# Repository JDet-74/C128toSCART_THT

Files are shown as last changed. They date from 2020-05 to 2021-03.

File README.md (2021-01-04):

<h2>C128toSCART_THT</h2>

<p>This is a project to connect a&nbsp;Commodore C128 8-bit computer to a display with a SCART input device.</p>

<p>Here, you can find some documents to build the video adapter PCB which I developed.</p>

<p>Get the information, build your PCB and have some 8-bit fun.</p>

<p>I started this project because I wanted to use my old Commodore 128DCR with a modern display.</p>

<p>I only had&nbsp;a 30-year-old SCART-cable that combines the 9 pin D-SUB RGBI connector and the 8 pin DIN connector for audio and video output.</p>

<p>I reverse engineered the old cable and got into this content. The Commodore 128DCR has 2 separate video chips.</p>

<p>The VIC-chip that provides the 40 column video mode in a composite and s-video signal and the VDC-chip that provides the 80 column video mode in a 5V TTL level RGBI signal.&nbsp;</p>

<p>It is possible to use the C128 with 2 displays. One display that supports RGBI for the 80 column mode and another display that supports composite or s-video for the 40 column mode.</p>

<p>I wanted just one display that supports both and that was the reason why I used&nbsp;the SCART interface.</p>

<p>The SCART standard provides RGB, composite, s-video and component (Y Pb&nbsp;Pr). It is possible to use only one display and to switch between the two column modes.</p>

<p>I researched and created a PCB that converts the digital 5V TTL 4 bit RGBI signal into a analog RGB signal. For that I used a <span style="font-family: Arial, Helvetica, sans-serif; font-size: 12px;">EEPLD (electrical erasable&nbsp;</span>&nbsp;programmable logic device) that converts the 4 bit RGBI color code into a 6 bit RGB color code. A resistor network adapts the TTL level to the analog RGB voltage level.</p>

<p>This all happens between the 9 pin D-SUB connector and the manual switch.</p>

<p>The composite or s-video signal goes from the C128 DIN connector straight through the switch.</p>

<p>The SWITCH is just for switching the right signals to the right pins of the SCART connector to run the display device.</p>

<p>In the following directories you will find the necessary files for the PCB, the soldering, the part list, the housing and the switch-extension.</p>

## Contact
For any questions (technical / experience), please use the issue tracking system of github.

## Pictures
<p>Now some pictures of the project.&nbsp;Enjoy!</p>

<hr />
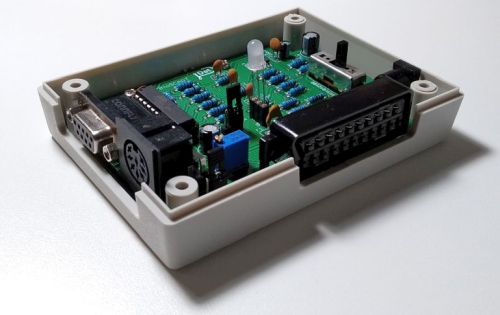
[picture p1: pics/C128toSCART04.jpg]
PCB in open housing


<p>This is the open housing with the soldered PCB mounted in</p>

<hr />
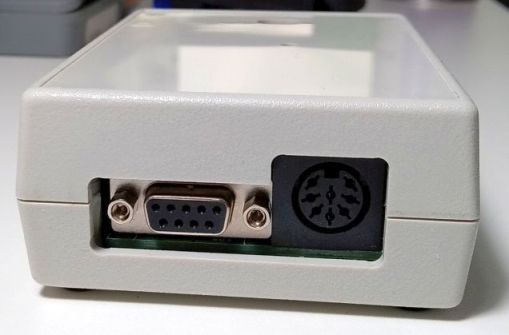
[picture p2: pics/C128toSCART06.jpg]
closed housing - connections to the C128


<p>The closed housing with the connections sockets to the C128 (D-SUB for RGBI &amp; DIN for the A/V Plug)</p>

<hr />
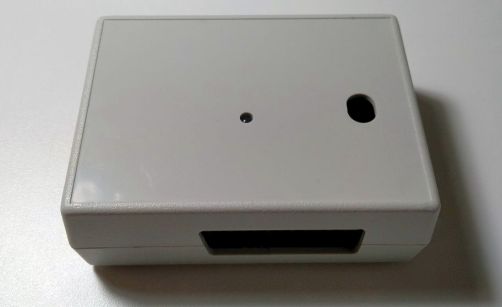
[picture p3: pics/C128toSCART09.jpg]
closed housing - the longhole for the switch-extension


<p>The view from above - the hole for the 3mm DUO-LED and the long hole for the switch-extension.<br />
It is also possible to toggle the switch with a pencil or something else ;)</p>

<hr />
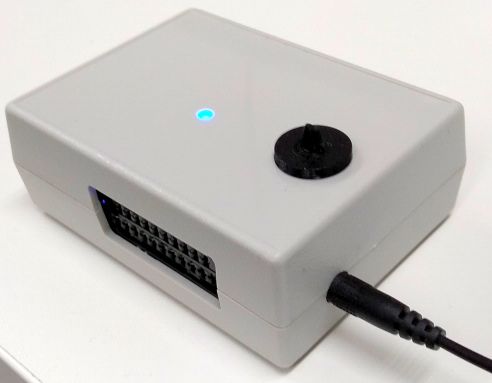
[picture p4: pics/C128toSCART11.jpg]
housing LED blue (80 column mode)


<p>The 3D printed switch-extension is plugged in.<br />
Device switched in 80 column mode (the blue LED indicates that) powered from a 5V USB-Charger with a barrel plug.<br />
It is possible to use the RGBI/CGA output of an&nbsp;old PC with a CGA graphic card to&nbsp; use a SCART display device.&nbsp;</p>

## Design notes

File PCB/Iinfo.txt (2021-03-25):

Take the Gerber_C128toSCART_V3.ZIP file and order the PCBs by your PCB manufaturer.
I ordered it be www.jlcpcb.com. The Gerber_C128toSCART_V3.ZIP contains the gerber files and this is all you need.

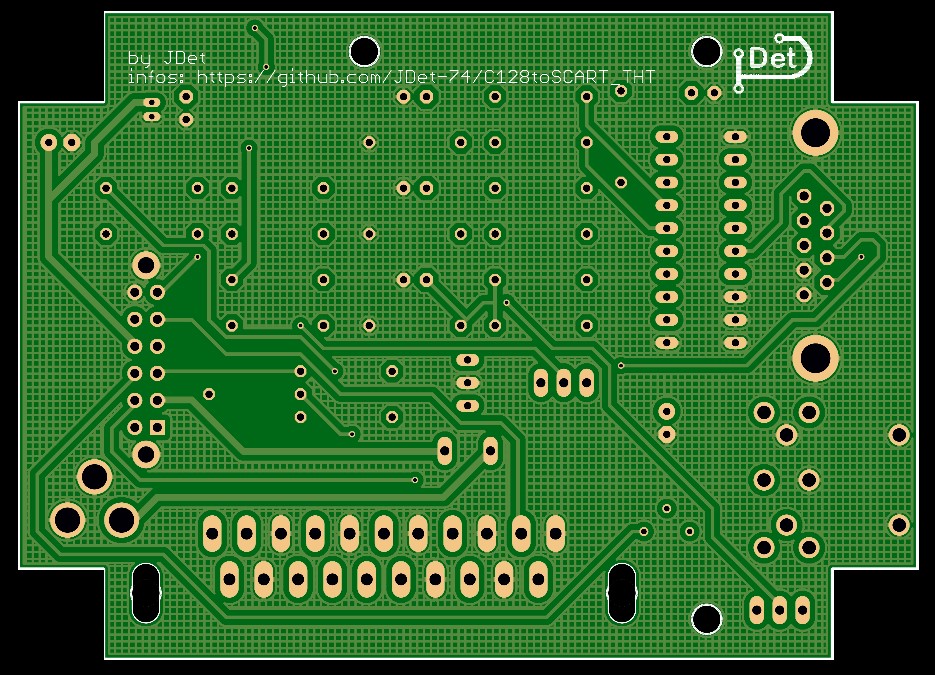
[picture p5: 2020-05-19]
PCB/PCB-C128toSCART-BOT.jpg

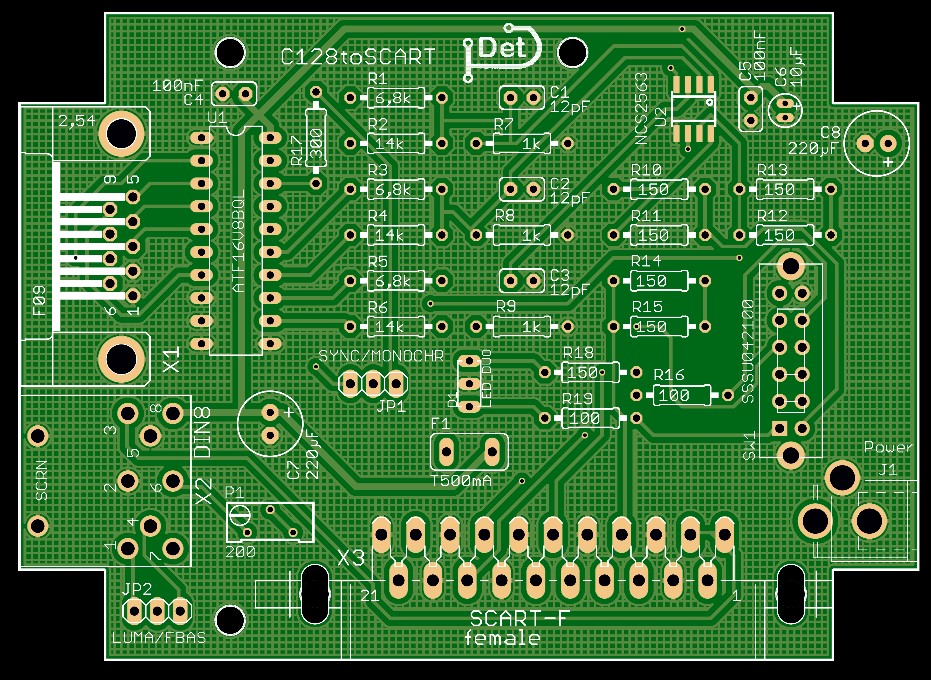
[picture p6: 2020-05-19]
PCB/PCB-C128toSCART-TOP.jpg

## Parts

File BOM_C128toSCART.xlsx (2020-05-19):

Pos | Name | Stück | Artikel # | Lieferant | Bezeichnung:
1 | option | 1 | RND 455-00959 | www.reichelt.de | Kunststoffgehäuse, 111 x 82,5 x 38 mm
2 | option | 1 | HS 25-14 | www.reichelt.de | Hohlstecker Knickschutz, Ø außen: 5,5 mm, Ø innen: 2,5 mm
3 | option | 1 | HSW 25-9 | www.reichelt.de | Hohlstecker ohne Knickschutz, Ø außen: 5,5 mm, Ø innen: 2,5 mm
4 | option | 2 | AK 218 SC | www.reichelt.de | D-SUB Kabel, 1:1, 9-pol., Stecker/Stecker, 1,8m
 | option | 1 | SBL 29065-100 | www.reichelt.de | Blechschrauben, PAN Head, PZD, 2,9 x 6,5 mm, 100 Stück
5 | option | 2 | MAS 80S | www.reichelt.de | DIN-Stecker 8-polig, Hufeisenform
6 | option | 1 | AK 315-10 | www.reichelt.de | Scart Kabel 21-pol Scart Stecker, 1 m
7 | R7-9 | 3 | C410696 | www.lcsc.com | Widerstand, Metallschicht, 1,0 kOhm, 0207, 0,6 W, 1%
8 | U1 | 1 | ATF 16V8BQL15 PU | www.reichelt.de | PLDs, 8 Makrozellen, 4,75 ... 5,25 V, DIL-20
9 | U1 | 1 | C2328 | www.lcsc.com | DIL20 Sockel (CHINA)
10 | option | 1 | RND 205-00643 | www.reichelt.de | RND Buchsenleiste, 3-pol, RM 2,54 mm
11 | JP1-2 | 2 | RND 205-00624 | www.reichelt.de | RND Stiftleiste, 3-pol, RM 2,54 mm
12 | P1 | 1 | 64Y-200 | www.reichelt.de | Präzisionspotentiometer, 25 Gänge, stehend, 200 Ohm
13 | option | 2 | JUMPER 2,54GL RT | www.reichelt.de | Kurzschlussbrücke, rot, mit Grifflasche
14 | R2,4,6 | 3 | C410680 | www.lcsc.com | Widerstand, Metallschicht, 14 kOhm, 0207, 0,6 W, 1%
15 | R10-15,18 | 7 | C410679 | www.lcsc.com | Widerstand, Metallschicht, 150 Ohm, 0207, 0,6 W, 1%
16 | D1 | 1 | C330762 | www.lcsc.com | LED, 3 mm, bedrahtet, 3-Pin CC, rot/grün, 80 mcd, 80°
17 | C4-5 | 2 | C353912 | www.lcsc.com | Ceramic Disc Capacitors 100nF -20%~+80% 50V Through Hole
18 | C1-3 | 3 | C353907 | www.lcsc.com | Keramik-Kondensator 12P
19 | R17 | 1 | C410638 | www.lcsc.com | Widerstand, Metallschicht, 300 Ohm, 0207, 0,6 W, 1%
20 | D1 | 1 | C331054 | www.lcsc.com | LED, 5 mm, bedrahtet, 3-Pin, rot/grün, 100 mcd, 30°
21 | R16,19 | 2 | C410697 | www.lcsc.com | Widerstand, Metallschicht, 100 Ohm, 0207, 0,6 W, 1%
22 | C7-8 | 2 | C43318 | www.lcsc.com | 220uF 10V
23 | R1,3,5 | 3 | C410590 | www.lcsc.com | Widerstand, Metallschicht, 6,8 kOhm, 0207, 0,6 W, 1%
24 | C6 | 1 | C43846 | www.lcsc.com | 10uF 25V 4*5
25 | SW1 | 1 | C384610 | www.lcsc.com | Toggle Switch (ALPS) (CHINA)
26 | U2 | 1 | C97773 | www.lcsc.com | NCS2563 - VIDEO AMP (CHINA)
27 | X1 | 1 | C75749 | www.lcsc.com | DSUB-9 Buchse
28 | X2 | 1 | DIN-8 Buchse | www.restore-store.de | DIN-8 Buchse Hufeisenform
29 | X3 | 1 | SCART Buchse | www.restore-store.de | SCART Buchse
30 | J1 | 1 | DC BU25 90 | www.reichelt.de | Einbaubuchse, Ø außen: 6,3 mm, Ø innen: 2,5 mm
31 | F1 | 1 | C262050 | www.lcsc.com | PTC Sicherung

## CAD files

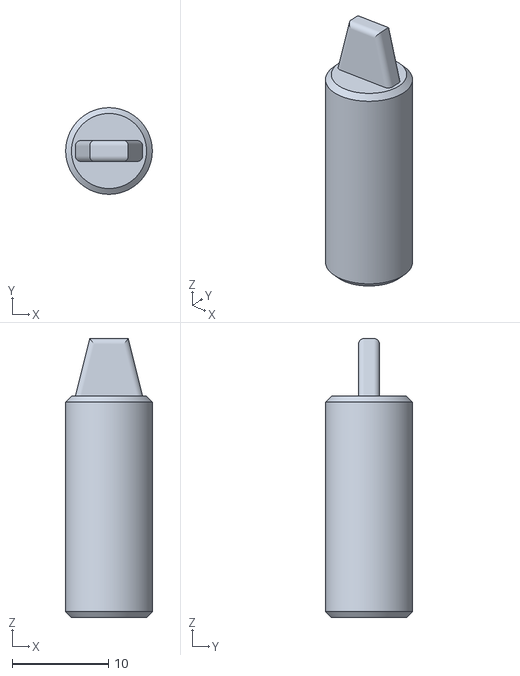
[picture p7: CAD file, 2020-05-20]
3DPrint/Schalterverlaengerung.stl
9.00 x 9.00 x 29.0

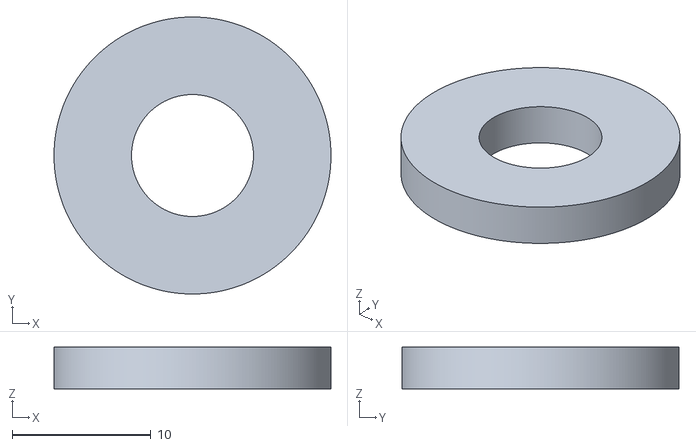
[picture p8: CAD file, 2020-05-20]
3DPrint/Gleitplatte.stl
20.0 x 20.0 x 3.00

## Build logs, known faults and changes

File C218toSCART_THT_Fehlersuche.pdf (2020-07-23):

# C128to SCART_THT

https://github.com/JDet-74/C128toSCART_THT

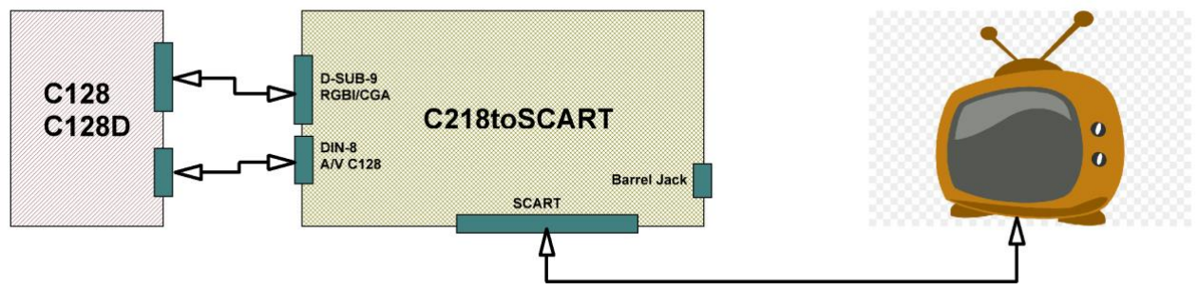
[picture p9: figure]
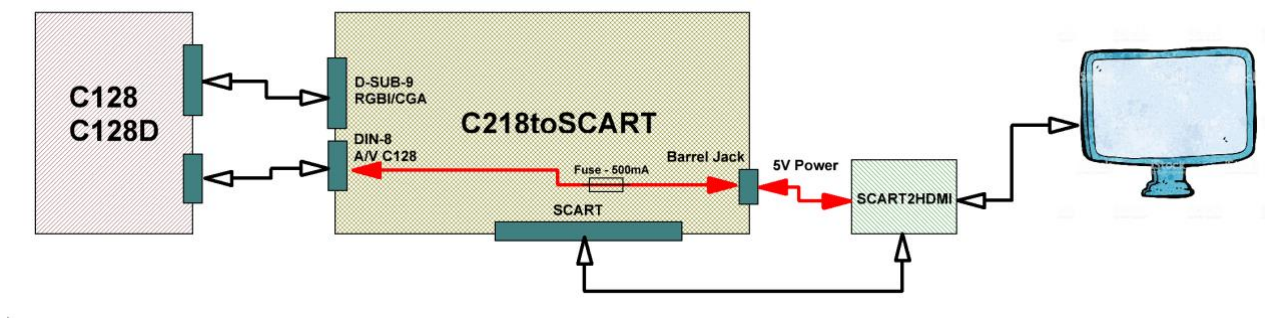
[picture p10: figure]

C128to SCART_THT | Seite: 1 von 11

### Fehlersuche / Fehlerbehebung (nur in Deutsch)

WICHTIGE INFORMATIONEN zum ANSCHLUSS!!!!

Anschluss 1 / Connection 1:

Anschluss 1 ist vermutlich der häufigste Anschluss, wenn ein C128 mit einem D-SUB-9 Kabel (1:1 Verbindung) und einem DIN-8 Kabel (1:1 Verbindung) an das C128toSCART angeschlossen wird.

In diesem Fall darf KEIN Power Supply an die Hohlstecker Buchse (Barrel Jack) angeschlossen werden, da der C128 +5V am PIN8 des DIN-8 Steckers zur Verfügung stellt.

Es wären ansonsten 5V des C128 und 5V des gesteckten Power Supplys parallel geschalten und würden miteinander konkurrieren.

Anschluss 2 / Connection 2:

Bei Anschluss Beispiel 2 kann über die Hohlstecker Buchse die 5V des C128 genutzt werden um ein anderes Gerät das 5V benötigt damit zu versorgen. Es dürfen jedoch nicht mehr als 500mA fließen. Eine automatisch rückstellende PTC Sicherung verhindert eine Überlastung.

https://github.com/JDet-74/C128toSCART_THT

Anschluss 3 / Connection 3:

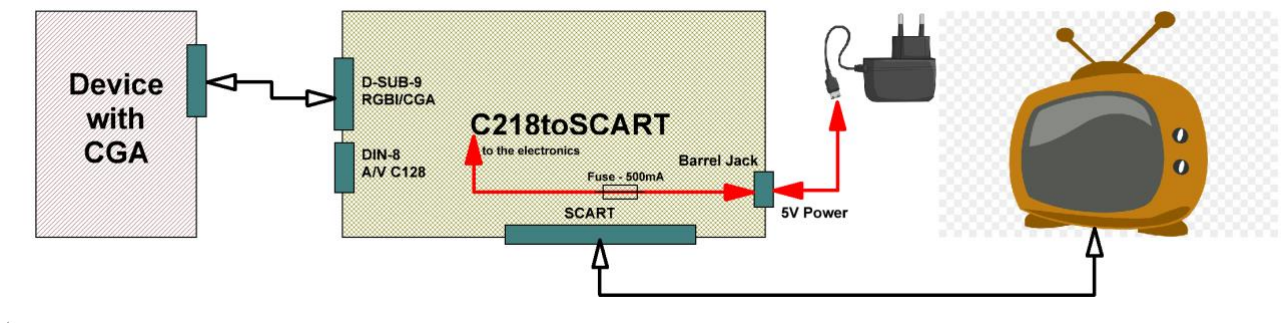
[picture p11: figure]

Bei diesem Anschlussbeispiel kann schließt man ein anderes Gerät das CGA Grafik Ausgang hat an das C128toSCART an. Nun muss man ein externes Power Supply an die Hohlstecker Buchse anschließen, damit die CGA2RGB Elektronik versorgt wird.

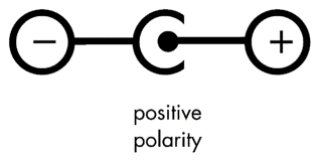
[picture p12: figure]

Polarität der Hohlstecker Buchse
polarity of the barrel jack

Fehler:

Kein Bild im 40 Zeichen Modus:

Wenn der Schiebeschalter OBEN steht ist der 40 Zeichen Modus aktiv und die rote LED sollte leuchten.

Wenn dies nicht funktioniert kann man wie folgt vorgehen:

- Steckt das DIN-8 Kabel ordentlich in beiden Geräten (C128 / C128toSCART)?
- Steckt das SCART Kabel ordentlich in beiden Geräten (C128 / C128toSCART)?
- Sind beide Kabel in Ordnung?
- Sind alle Lötstellen ordentlich und keine Schlüsse zu Masse / GND vorhanden?

Um ein Video / S-Video Signal an einem SCART Gerät anzuzeigen sollten folgenden Signale an der SCART Buchse des C128to SCART Geräts anliegen:

Pin SCART Buchse: | Signal: | Herkunft:
19 | Video (FBAS/Composite) / LUMA (1Vss) | Pin 4 / Pin 1 DIN-8 Buchse
17 | Masse / GND (Video) | Massefläche Platine
18 | Masse / GNDs (LUMA & Austastung) | Massefläche Platine
16 | Austastung (Fast Blanking) (0 – 0,4V) Video Betrieb | Schiebeschalter
15 | CHROMA (1Vss) | Pin 6 DIN-8 Buchse über P1
13 | Masse / GND (CHROMA) | Massefläche Platine

Nachfolgend können diese Signalwege mit einem Multimeter im Durchgangsprüfer- oder Widerstands-Modus nachgeprüft werden.

INFO: die „weiß“ gekennzeichneten Leiterbahnen sind der jeweiligen Leiterbahnenweg!

https://github.com/JDet-74/C128toSCART_THT

Der Schiebeschalter muss OBEN im 40 Zeichen Modus stehen.

FBAS / Composite – ist die Verbindung O.K.?

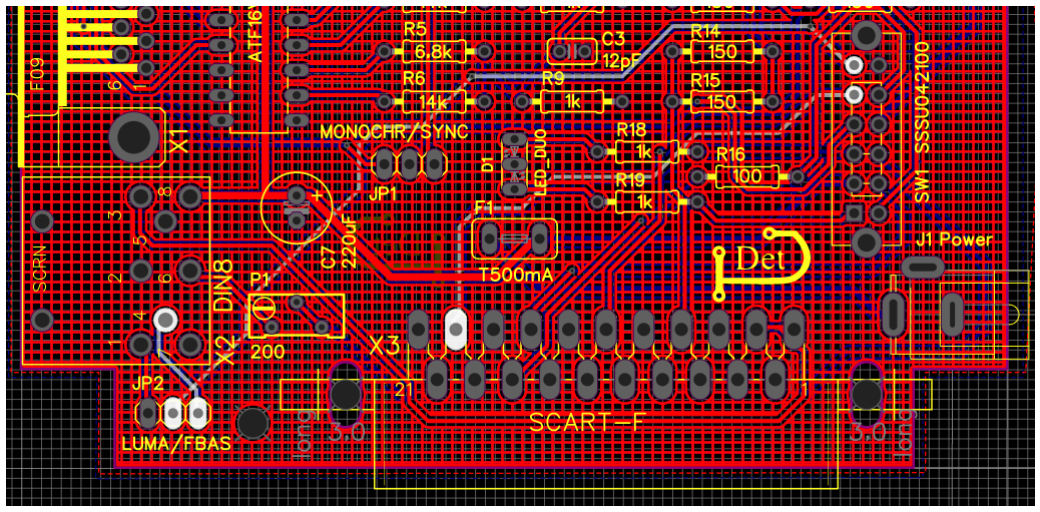
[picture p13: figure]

Pin 4 an der DIN-8 Buchse empfängt COMPOSITE / FBAS das vom C128 gesendet wird.

Prüfe mit dem „Durchgangsprüfer“ des Multimeters ob die Verbindung von Pin4 zu Pin 19 der SCART Buchse vorhanden ist, wenn der Schiebeschalter OBEN steht und der JUMPER den mittleren und rechten Pin von JP2 verbindet. Wenn dies der Fall ist kann auch noch der Widerstand der Verbindung ermittelt werden. Falls der Widerstandswert zu groß erscheint können die Lötstellen die den „weißen“ Leiterbahnenweg betreffen überprüft werden.

Des Weiteren kannst du überprüfen dass kein Durchgang der Signalleitungen zu Masse / GND vorhanden sind. Dies würde auf einen Schluss gegen Masse hinweisen. Überprüfe dies bei allen Signalleitungen mit denen du Probleme hast im Widerstands- oder Durchgangsprüfer-Modus deines Multimeters.

S-Video - LUMA (Bildinformation + Synchronisationssignal) – ist die Verbindung O.K.?

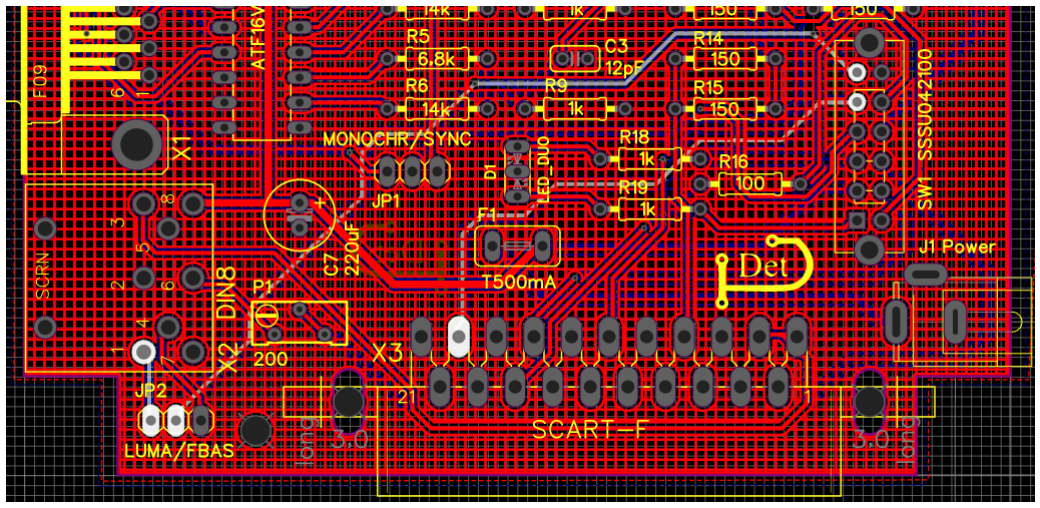
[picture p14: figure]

https://github.com/JDet-74/C128toSCART_THT

Der Weg dieser Verbindung identisch zu der COMPOSITE / FBAS Verbindung, bis auf den Unterschied, dass der JUMPER den linken und den mittlerem Pin von JP2 verbindet.

Wenn also der Weg von COMPOSITE / FBAS in Ordnung ist muss nur geprüft werden, ob von Pin1 der DIN-8 Buchse zu JP2 linker Pin eine gute Verbindung besteht.

Ansonsten prüfe mit dem Durchgangsprüfer ob bei gestecktem JUMPER eine Verbindung von Pin1 von DIN-8 nach Pin 19 der SCART Buchse besteht. Falls nicht, überprüfe die Lötstellen auf dem Leiterbahnenweg.

S-Video – CHROMA (Farbinformation) – ist die Verbindung O.K.?

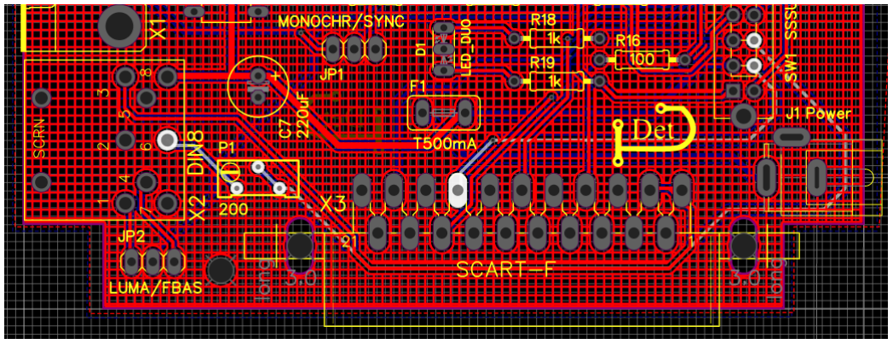
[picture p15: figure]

Pin6 der DIN-8 Buchse empfängt vom C128 das CHROMA Signal.

Überprüfe mit dem Durchgangsprüfer, ob der Weg von Pin 6 DIN-8 nach Pin 15 der SCART Buchse niederohmig vorhanden ist. Das CHROMA Signal kann mit P1 geschwächt werden. Falls kein Farbsignal vorhanden sein sollte, kann der Poti P1 auch zu Testzwecken gebrückt werden. Entweder auslöten und eine Drahtbrücke einlöten, oder eine Lötbrücke auf der Leiterbahn Unterseite anbringen und die beiden Pins des P1 verbinden.

Austastung (Fast Blanking) – ist die Verbindung O.K.?

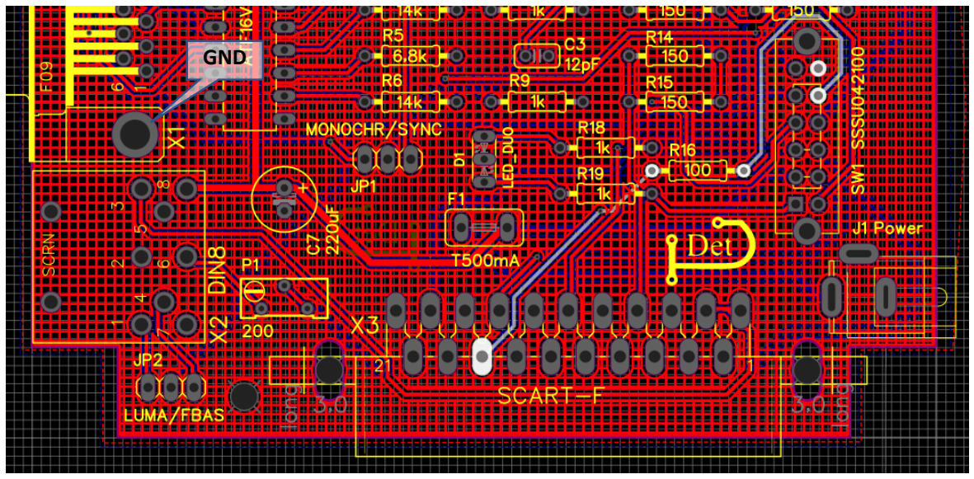
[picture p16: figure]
GND

Messe gegen Masse / GND (z.B. Befestigungsloch X1) ob an Pin 16 ca. 100 Ohm Widerstand sind.

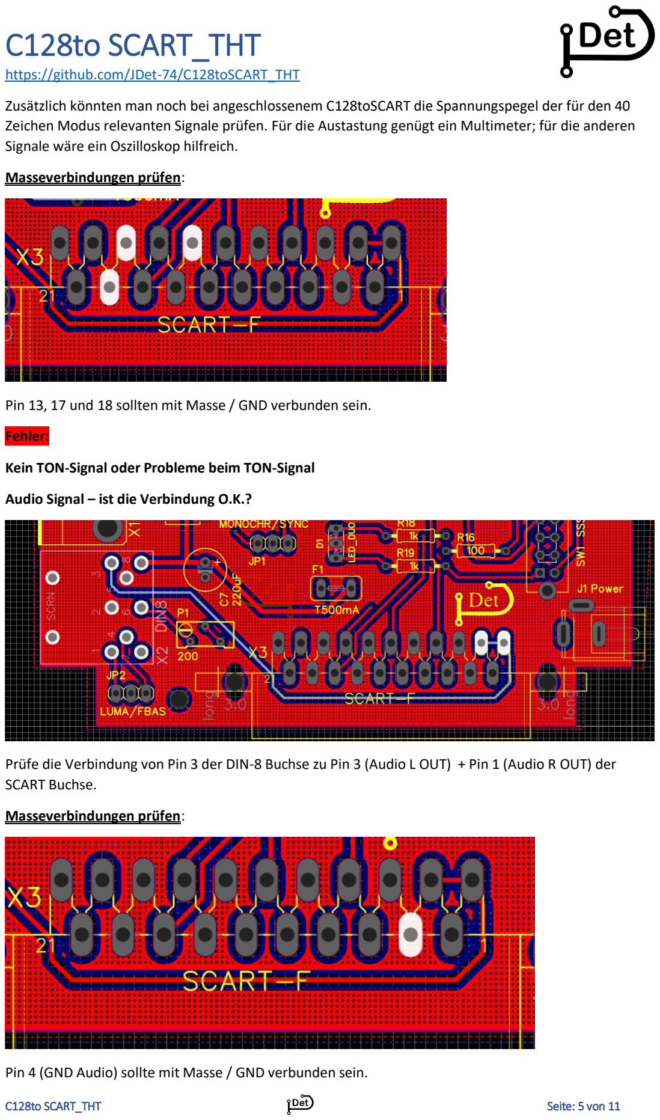
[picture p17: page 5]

https://github.com/JDet-74/C128toSCART_THT

Zusätzlich könnten man noch bei angeschlossenem C128toSCART die Spannungspegel der für den 40 Zeichen Modus relevanten Signale prüfen. Für die Austastung genügt ein Multimeter; für die anderen Signale wäre ein Oszilloskop hilfreich.

Masseverbindungen prüfen:

Pin 13, 17 und 18 sollten mit Masse / GND verbunden sein.

Fehler:

Kein TON-Signal oder Probleme beim TON-Signal

Audio Signal – ist die Verbindung O.K.?

Prüfe die Verbindung von Pin 3 der DIN-8 Buchse zu Pin 3 (Audio L OUT) + Pin 1 (Audio R OUT) der SCART Buchse.

Masseverbindungen prüfen:

Pin 4 (GND Audio) sollte mit Masse / GND verbunden sein.

https://github.com/JDet-74/C128toSCART_THT

Fehler:

Kein Bild im 80-Zeichen Modus:

Wenn der Schiebeschalter UNTEN steht ist der 80 Zeichen Modus aktiv und die blaue LED sollte leuchten.

Wenn dies nicht funktioniert kann man wie folgt vorgehen:

- Steckt das D-SUB-9 Kabel ordentlich in beiden Geräten (C128 / C128toSCART)?
- Steckt das SCART Kabel ordentlich in beiden Geräten (C128 / C128toSCART)?
- Sind beide Kabel in Ordnung?
- Sind alle Lötstellen ordentlich und keine Schlüsse zu Masse / GND vorhanden?
- Steckt der ATF16V8 PLU IC richtig im IC-Sockel?

Wenn dies alles passt kann man mit einem Multimeter und elektronischer Erfahrung folgendes bei abgestecktem C128toSCART prüfen:

INFO: die „weiß“ gekennzeichneten Leiterbahnen entsprechen dem jeweiligen Leiterbahnenweg!

Der Schiebeschalter muss UNTEN im 80 Zeichen Modus stehen.

SYNC Signal – ist die Verbindung O.K.?

Monchrome SYNC Signal vom C128 – checken!

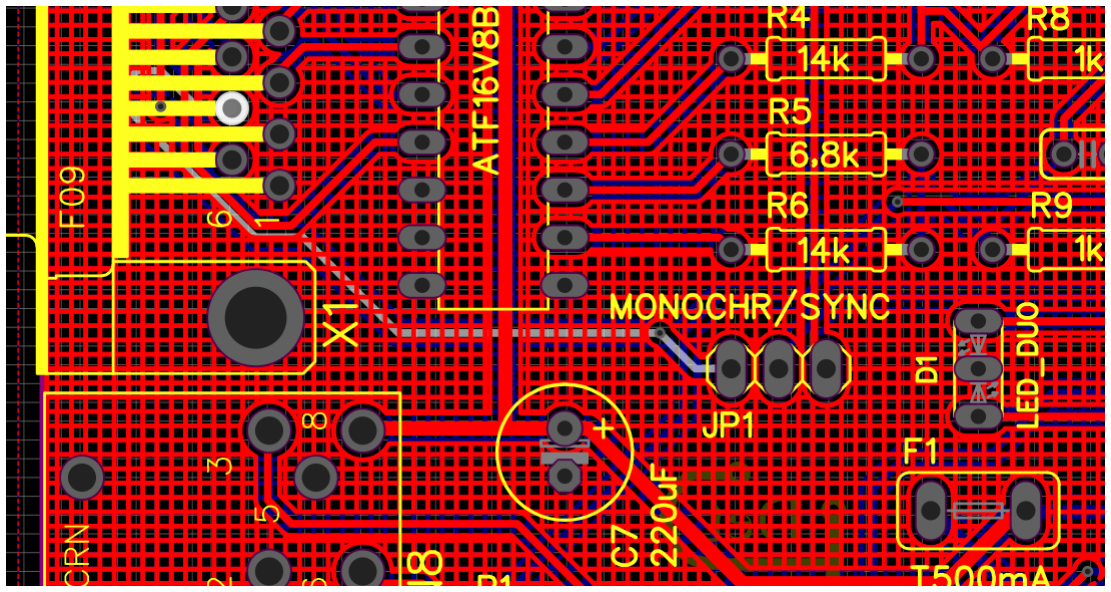
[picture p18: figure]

Prüfe die Verbindung von D-SUB-9 Pin 7 zu JP1 Pin links. Dort müsste ein ca. 1V Monochrome Signal vom C128 gesendet werden.

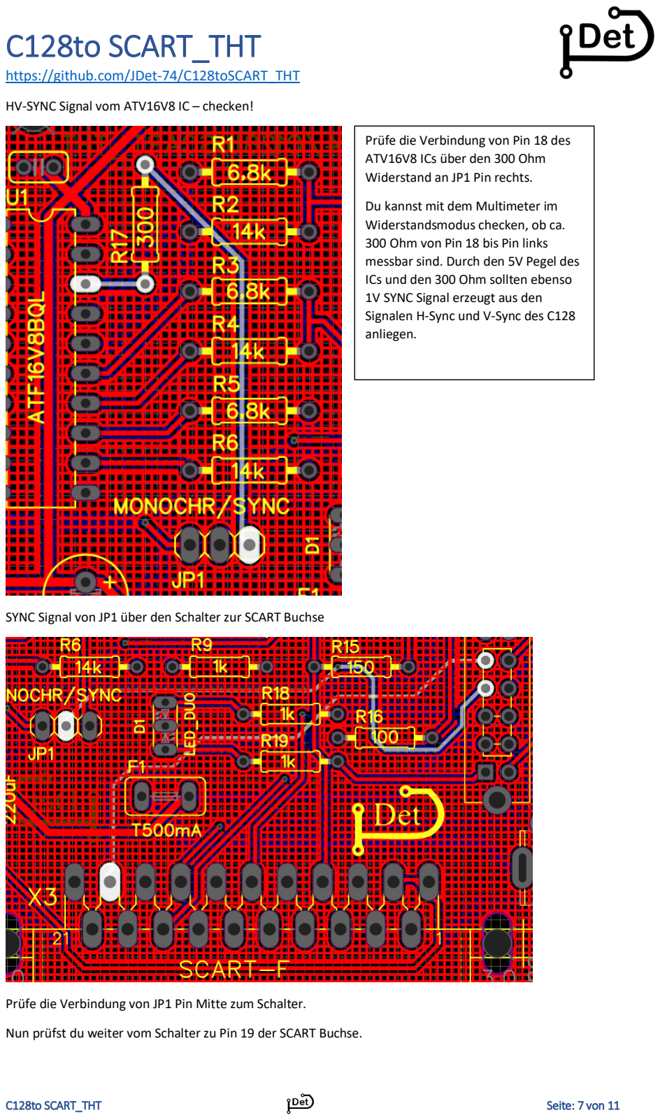
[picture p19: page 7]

https://github.com/JDet-74/C128toSCART_THT

HV-SYNC Signal vom ATV16V8 IC – checken!

SYNC Signal von JP1 über den Schalter zur SCART Buchse

Prüfe die Verbindung von JP1 Pin Mitte zum Schalter.

Nun prüfst du weiter vom Schalter zu Pin 19 der SCART Buchse.

Prüfe die Verbindung von Pin 18 des ATV16V8 ICs über den 300 Ohm Widerstand an JP1 Pin rechts.

Du kannst mit dem Multimeter im Widerstandsmodus checken, ob ca. 300 Ohm von Pin 18 bis Pin links messbar sind. Durch den 5V Pegel des ICs und den 300 Ohm sollten ebenso 1V SYNC Signal erzeugt aus den Signalen H-Sync und V-Sync des C128 anliegen.

https://github.com/JDet-74/C128toSCART_THT

Die RGB Verbindungen zum Video Verstärker prüfen.

Prüfe nacheinander die Verbindungen von RGB zum Video Verstärker.

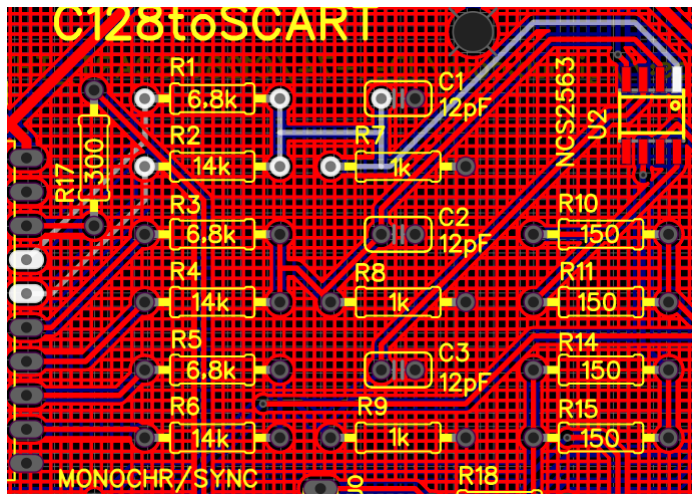
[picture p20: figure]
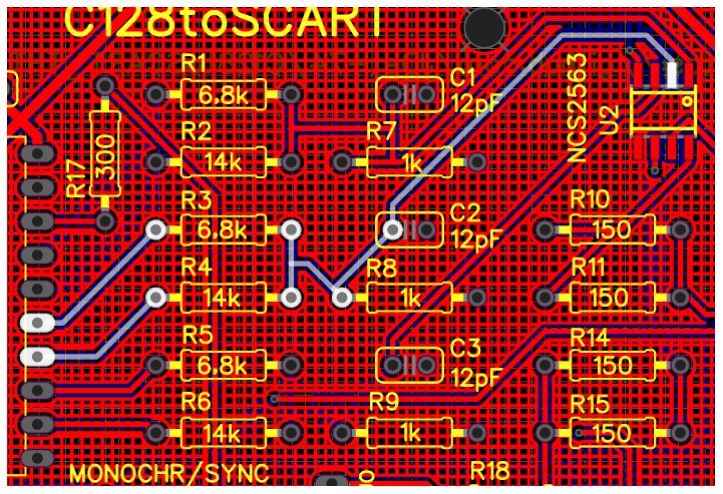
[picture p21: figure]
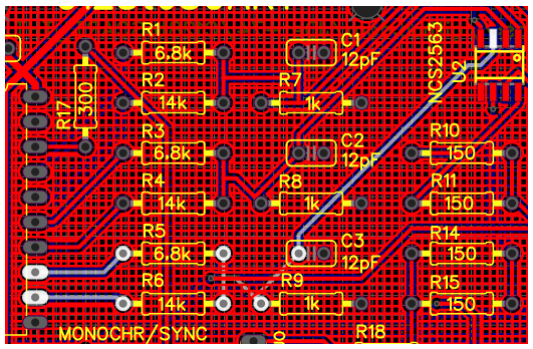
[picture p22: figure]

Danach können die RGB Verbindungen zur SCART Buchse geprüft werden.

Die GRÜN Verbindung zum Video AMP.

Die ROT Verbindung zum Video AMP.

Die BLAU Verbindung zum Video AMP.

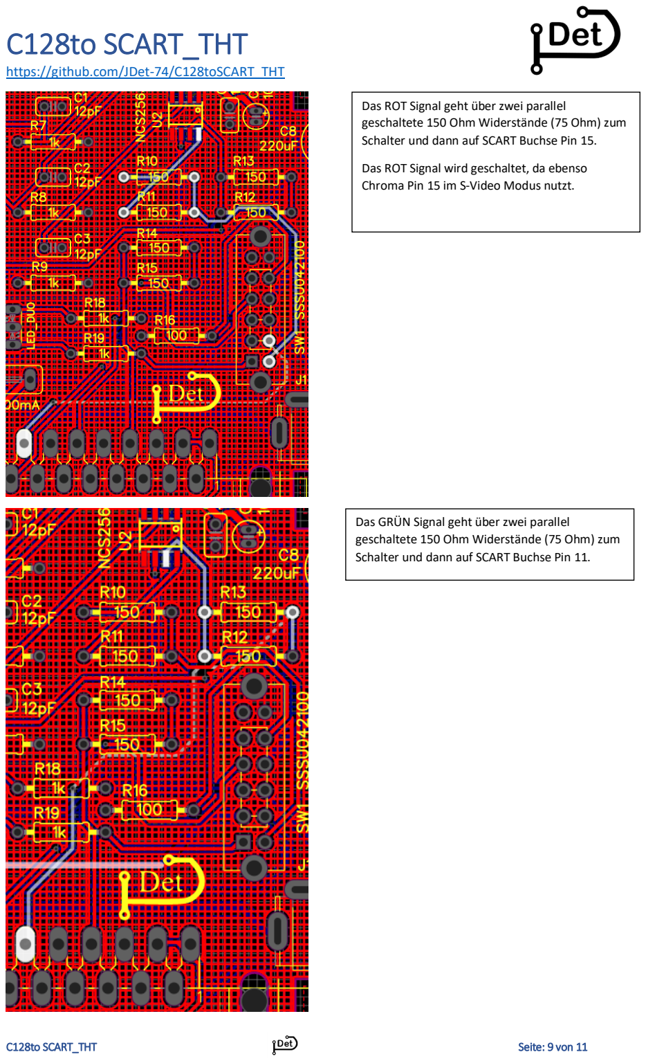
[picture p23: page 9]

https://github.com/JDet-74/C128toSCART_THT

Das ROT Signal geht über zwei parallel geschaltete 150 Ohm Widerstände (75 Ohm) zum Schalter und dann auf SCART Buchse Pin 15.

Das ROT Signal wird geschaltet, da ebenso Chroma Pin 15 im S-Video Modus nutzt.

Das GRÜN Signal geht über zwei parallel geschaltete 150 Ohm Widerstände (75 Ohm) zum Schalter und dann auf SCART Buchse Pin 11.

https://github.com/JDet-74/C128toSCART_THT

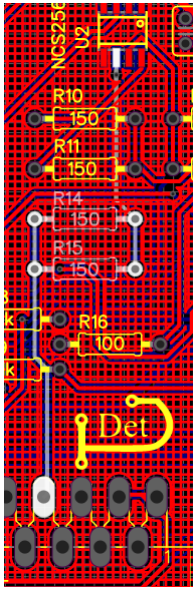
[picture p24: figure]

Spannungsmessung an den ICs

Der ATF16V8 PLD sowie auch der NCS2563 Video AMP IC sollten mit 5V Gleichspannung versorgt werden. Prüfe die Spannung mit dem Multimeter im Geichspannungs-Modus (DC).

Die weißen Markierungen sind die Messpunkte.

Das BLAU Signal geht über zwei parallel geschaltete 150 Ohm Widerstände (75 Ohm) auf SCART Buchse Pin 7.

Natürlich sollte auch abschließend geprüft werden, dass es die richtigen Widerstände sind und dass die Lötstellen gut sind.

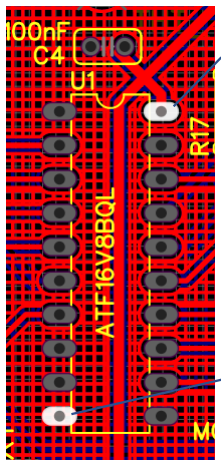
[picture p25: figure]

+5V

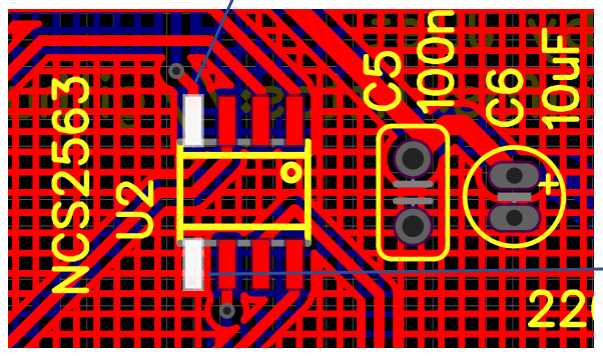
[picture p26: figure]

GND

+5V

GND https://github.com/JDet-74/C128toSCART_THT

Abschließen kann noch der „Fast Blanking“ Pegel geprüft werden.

Wenn das TV Geräte am SCART Eingang in den RGB Modus geschaltet werden soll, muss ein Spannungspegel von 1-3V an Pin 16 der SCART Buchse anliegen.

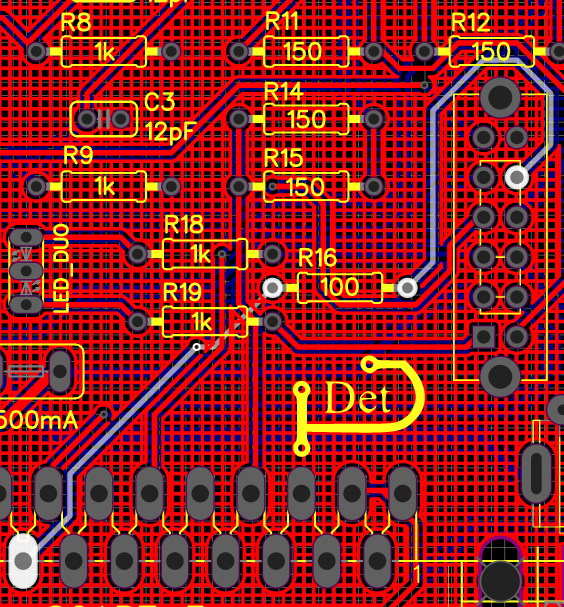
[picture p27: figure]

ZU LETZT … wenn alle Verbindungen, Lötstellen, Widerstände und Kondensatoren korrekt sind und keine Schlüsse gegen Masse (GND) oder 5V (VCC) vorhanden sind … kann nur noch

1. Der ATF16V8 PLD IC falsch programmiert oder defekt sein.
2. Der NCS2563 Video AMP IC defekt sein.

Prüfe die Verbindung vom Schalter zu Pin 16 der SCART Buchse im Widerstandsmodus durch. Du solltest ca. 100 Ohm angezeigt bekommen.

Du kannst auch den Spannungspegel im Betrieb mit dem Multimeter messen.

Er sollte auf alle Fälle >1 Volt sein.

Der 100 Ohm Widerstand sollte eigentlich einen Spannungspegel von ca. 2,1 Volt erzeugen.

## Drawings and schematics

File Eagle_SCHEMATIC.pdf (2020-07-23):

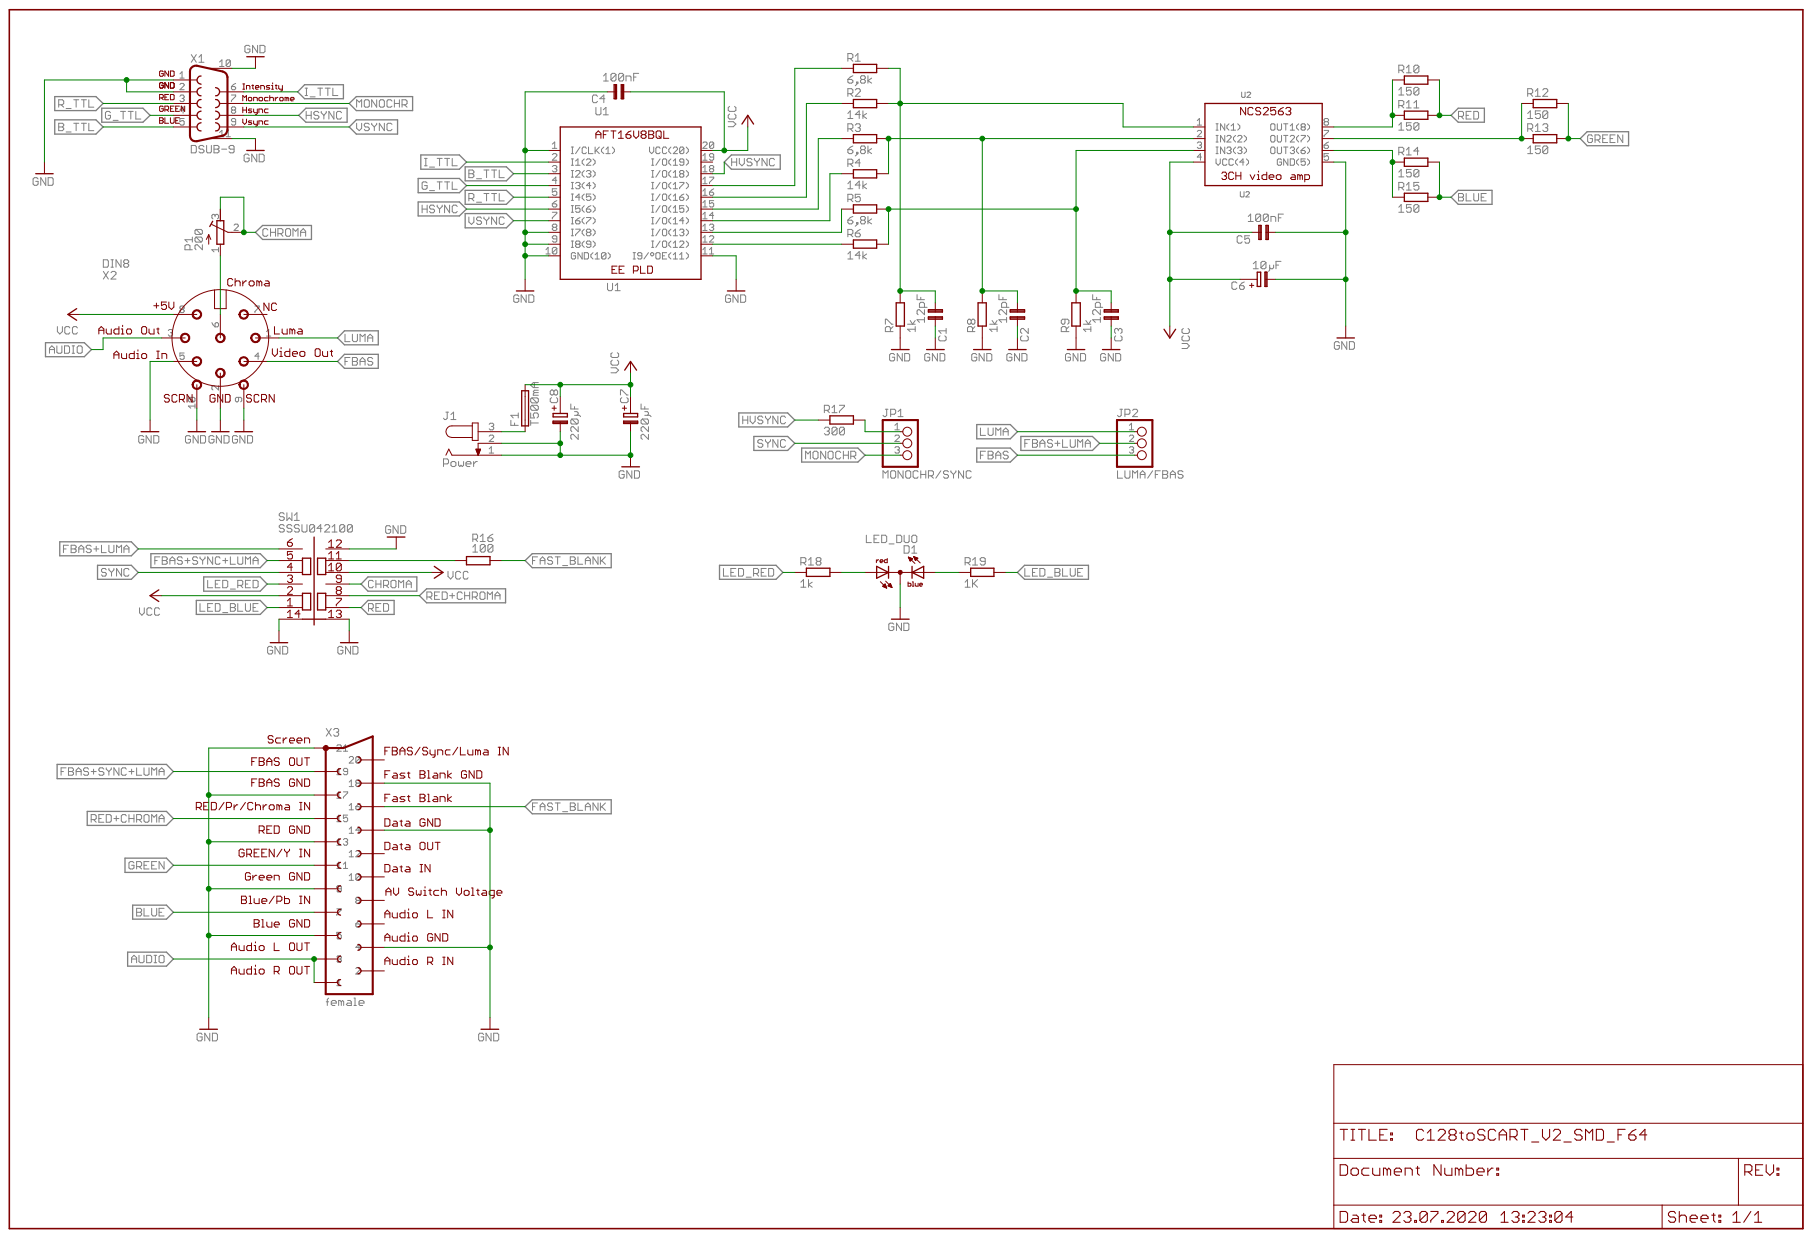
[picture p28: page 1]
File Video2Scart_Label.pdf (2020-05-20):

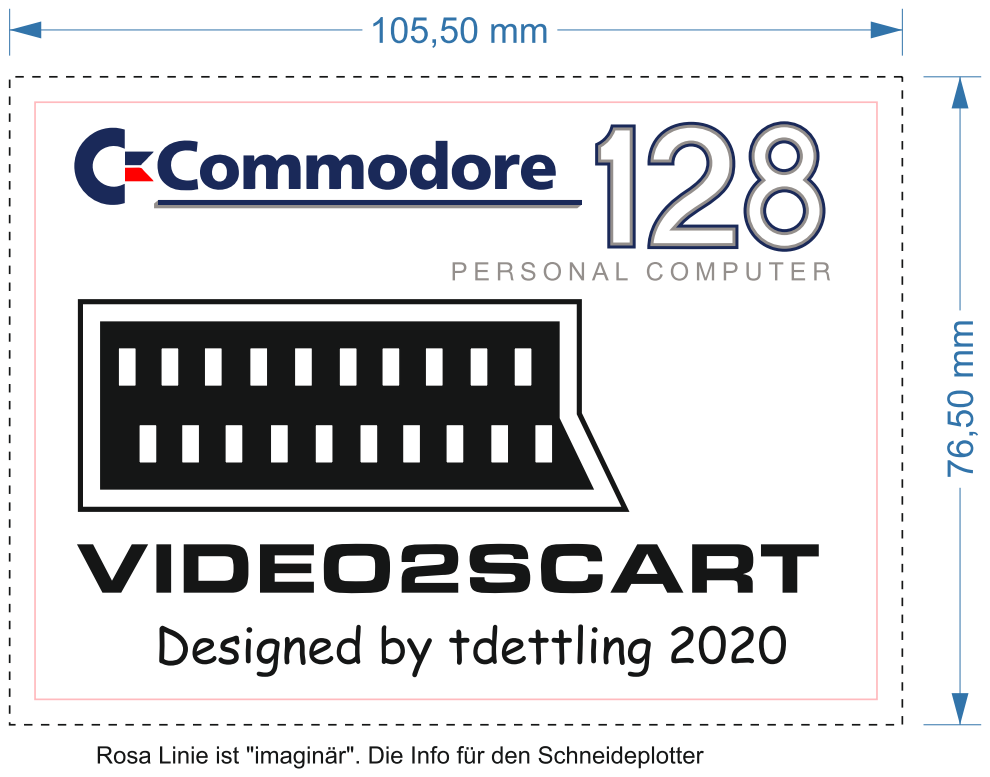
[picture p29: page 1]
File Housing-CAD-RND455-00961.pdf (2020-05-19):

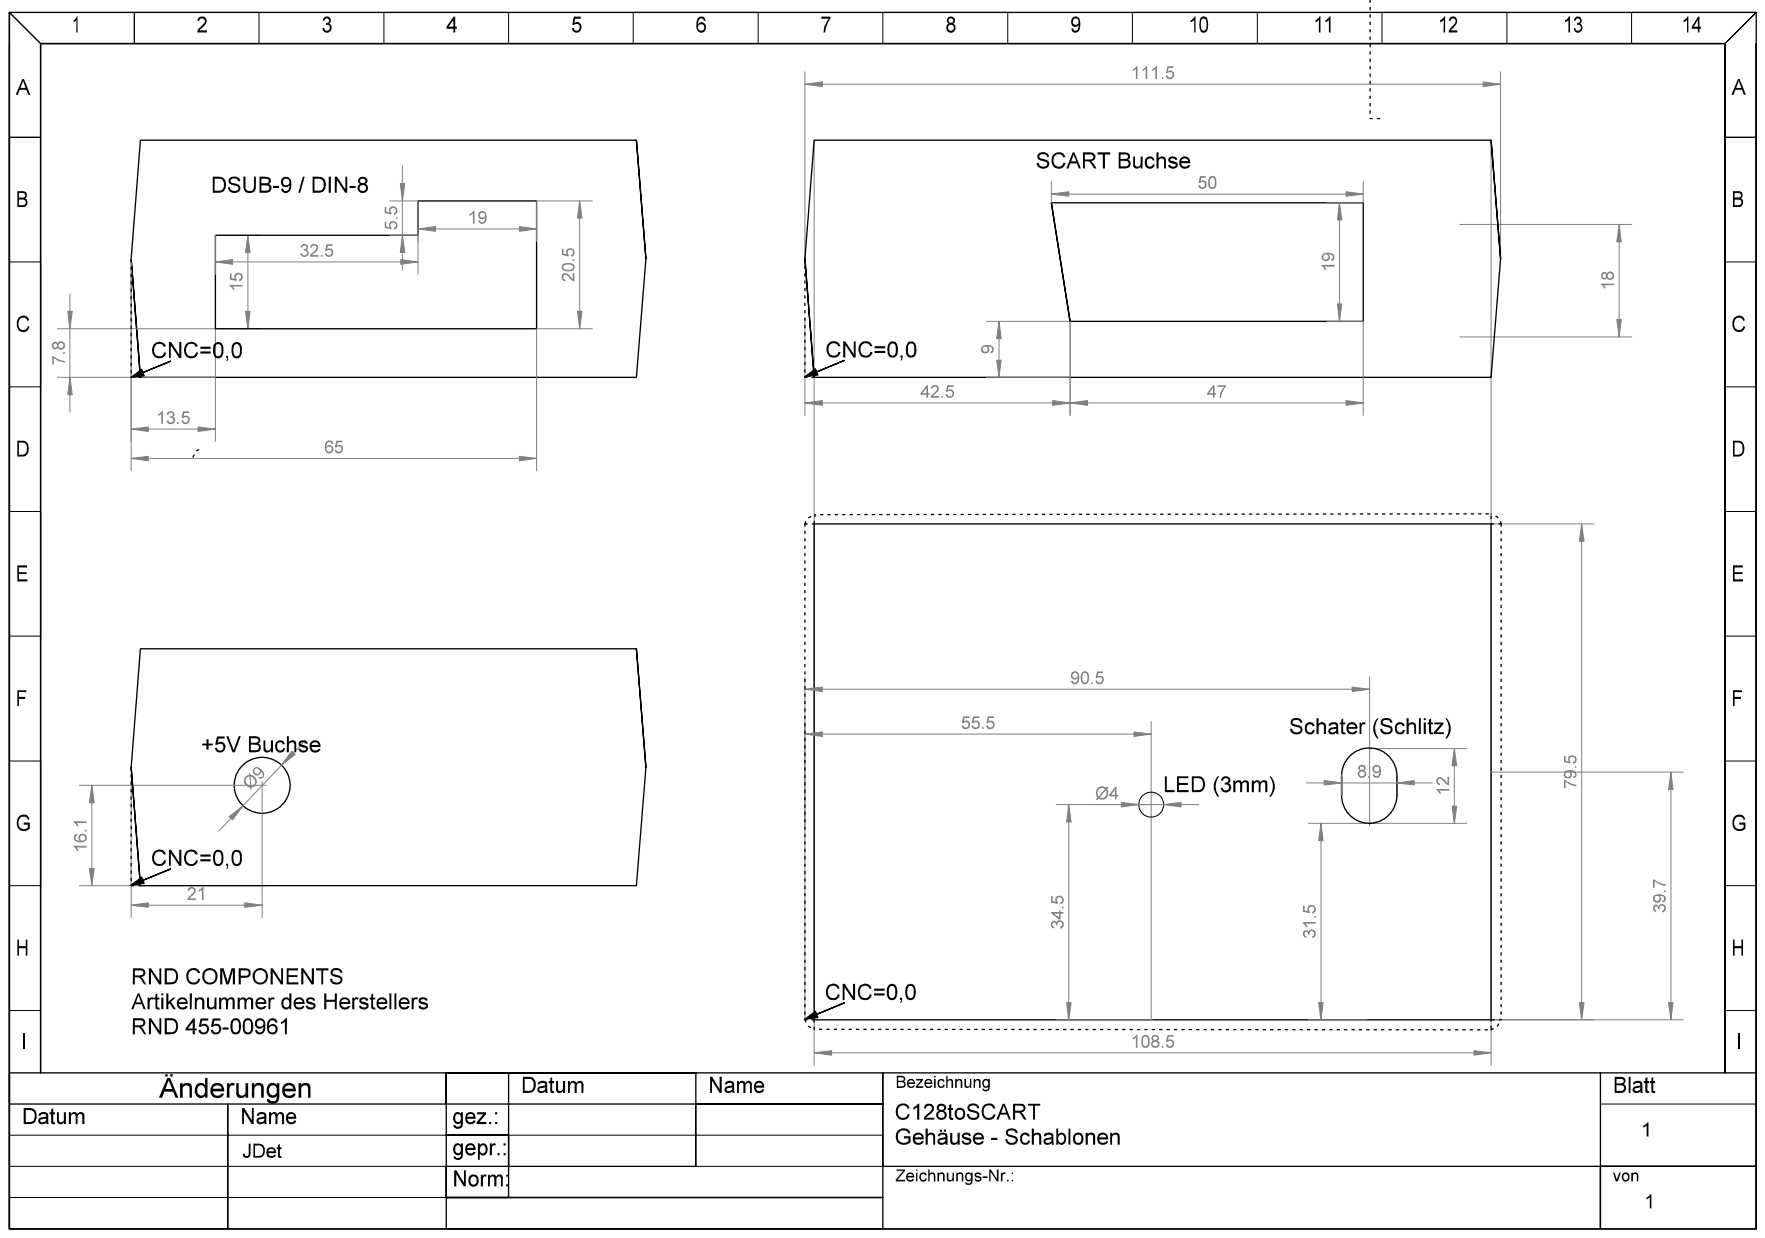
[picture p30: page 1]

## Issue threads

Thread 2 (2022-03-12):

C128 on TV screen

yovish, 2022-03-12:
Hello!

I am a fan of 8-bit microcomputers and an electronics hobbyist. I have built for my own use a cable for Commodore 128 that allows to view images from C128 on TV screen in 80 column mode and 40 column mode after proper switching. This cable is quite versatile as it supports these modes:
- 80 columns, RGBI color;
- 80 Columns Monochrome;
- 40 column Composite Video;
- 40 columns S-Video (additionally, it is possible to use ChromaFIX - 300Ohm resistor).

In my cable it is possible to control color saturation, separately for each component of primary colors (RGB) and separately the effect of Intensity on each color component.

I am wondering about a version with improvement of some colors, such as brown (dark-yellow in RGBI=1100) and dark gray (in RGBI=0001), which look bad on most screens.
I know that some CGA monitors automatically corrected the dark-yellow to brown.

I found a project on the internet that uses TTL ICs (74LS244, 74LS138 and 74LS86) to correct such colors, but I liked more your project that uses the ATF16V8BQL (GAL16V8) chip.
I programmed the GAL16V8D chip, with the Jedec file from your project, and analyzed how the output colors are set based on the RGBI data.
Since I would like to have more control, over the output signals, and I am not yet able to create a PLD file myself, could I ask for the file with which you created your Jedec (JED) file?

Best regards
Andrzej Bogacz (Yovish) from Poland
abogacz.pl@gmail.com

Translated with www.DeepL.com/Translator (free version)
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

JDet-74, 2022-03-13:
Hello Andrzej,

it looks like you are using a resistor ladder with some diodes for converting the RGBI signal to RGB signal.
Is it something like that, what H2Obsession did?
[https://sites.google.com/site/h2obsession/CBM/C128/rgbi-to-scart](url)

I just used the GAL to convert the 4 bit RGBI color scheme to the 6 bit (2 bit each color) RGB color scheme.

> Since I would like to have more control, over the output signals, and I am not yet able to create a PLD file myself, could I ask for the file with which you created your Jedec (JED) file?

To program the GAL I used the Windows Software WinCUPL.

Regards

Tilo

yovish, 2022-10-11:
Hello again!   And can I ask you to give me the PLD file created in WinCupl?  I am not able to do that yet.   Best regards  Andrzej Bogacz (Yovish)

        Dnia 13 marca 2022 13:17 Kernelpanic ***@***.***&gt; napisał(a):

 Hello Andrzej,
 it looks like you are using a resistor ladder with some diodes for converting the RGBI signal to RGB signal.
Is it something like that, what H2Obsession did?
 https://sites.google.com/site/h2obsession/CBM/C128/rgbi-to-scart
 I just used the GAL to convert the 4 bit RGBI color scheme to the 6 bit (2 bit each color) RGB color scheme.

 Since I would like to have more control, over the output signals, and I am not yet able to create a PLD file myself, could I ask for the file with which you created your Jedec (JED) file?

 To program the GAL I used the Windows Software WinCUPL.
 Regards
 Tilo

 —  Reply to this email directly,  github.com view it on GitHub , or  github.com unsubscribe .  Triage notifications on the go with GitHub Mobile for  apps.apple.com iOS  or  play.google.com Android .
  You are receiving this because you authored the thread. Message ID:  &lt;JDet-74/C128toSCART_THT/issues/2/1066089578 @ github . com&gt;
